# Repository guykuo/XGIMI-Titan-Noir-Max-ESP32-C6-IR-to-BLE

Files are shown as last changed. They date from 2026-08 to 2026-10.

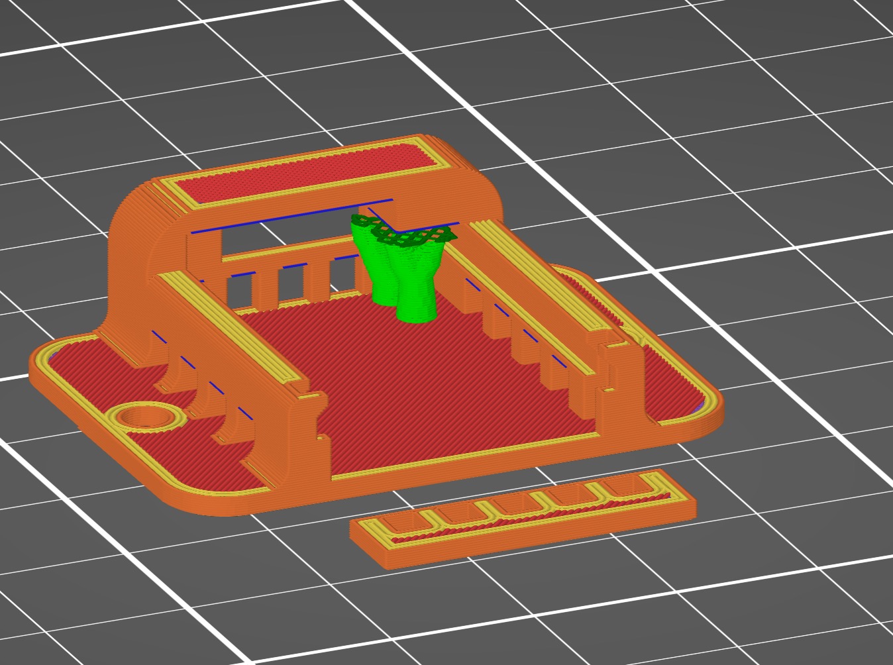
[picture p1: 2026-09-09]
esp32-c3-with-OLED-mount-slim/where_to_add_support_for_print.jpg

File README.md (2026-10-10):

# XGIMI Titan Noir IR Remote via ESP32

banner for git

Titan Noir projectors lack IR control capability and only accept bluetooth signals. This project works around that limitation by translating infrared signals into bluetooth commands the Titan Noir projectors accept. Typical use is to add an Xgimi Titan Noir to a universal IR remote. Depending on which IR code set you choose, you can add as a completely new projector or have the XTN projector masquerade as an existing projector already in your remote. This project runs on low cost ESP32 board.

## Requirements

*   A BlueTooth BLE Capable ESP32 Board. Two boards detailed here are...
    * ESP32-C3 SuperMini dev board with integrated 0.42-inch OLED display (my preferred board)
    * ESP32-C6-WROOM-1 (also good choice)

*   IR sensor module (three pin) for ESP32
    
*   XGIMI Titan Noir Max and its original Bluetooth remote
    
*   Windows, macOS or Linux computer with Bluetooth and Python 3.14 or newer
    
*   Data capable USB cable

This project implements IR translation to Xgimi Titan Noir bluetooth. The parent fork uses Home Assistant HID connectivity. Although Home Assistant has been retained in this project, it is not discussed here. Please see mrmachine's original github if you need _Home Assistant_ usage information.

Turning on the Xgimi Titan Noir projector requires use of the original Xgimi remote wake token. This translator can acquire that token by sniffing your original remote with the ESP32. 

Optionally, you can perform a more tedious, manual capture of your remote's wake token. Then, process that hexadecimal sequence into a secrets.yaml file. It is much easier to skip that process and let the translator ESP32 sniff and capture the wake token.
  
## What You Will Accomplish
Getting the translator to work requires you to...

* Choose which IR code set to translate
* Obtain ESP32 board and IR sensor to be this translator
* Connect ESP32 board to IR sensor (three wires)
* Create a copy of make-esp32-TEMPLATE.yaml
* Rename it something like make-my-translator.yaml
* Edit make-my-translator.yaml to specify name for your remote, which ESP32 board you are using, and which IR translation map.
* Create compiler evironment
* Compile your new ESP32 firmware and flash it to your ESP32 board.
* Set up your universal remote to use the IR mapped codes. 
       (If you chose an IR mapping which matches a projector already in your remote, 
       your remote can simply control the XTN as that existing projector)

# Layout of this Git
Project Git is arranged as below. You will find make, hardware, and IRmap files that are combined to create your own combination of IR code set translation and particular ESP32 board the translator is to run upon.
project git layout

Available hardware boards are in ir-common-kuo/ subdirectory.

## IR Profiles
This translator project has several "factory" IR profiles built-in. You and can also learn up to five new IR remote profiles if none of the factory profiles are suitable.

The "factory" IR profiles, were selected to avoid conflicts in a home theater.
One should usually choose one that does not conflict with existing devices in your system.

An alternative strategy is to intentionally select a projector that is already configured in your universal remote but being replaced.
This lets the Titan Noir masquerade as the old projector without reconfiguring your universal remote. However, the old projector cannot be
simultaneously used under masquerading strategy.

These "factory" IR profiles have known working IR code sets ...

| | |
| :--- | :--- |
| **benq-w5800** | BenQ W5800 projector |
| **epson-pro-cinema-LS1200** | Epson Projectors |
| **hisense-50u6g** | Hisense 50U6G TV |
| **jvc-hr-S9600u** | JVC HR-S9600U VCR |
| **jvc-rs2-codeset-A** | JVC Projectors code set A - default | 
| **jvc-rs2-codeset-B** | JVC Projectors code set B - alt code set | 
| **LG-cinebeam-hu810p** | LG Cinebeam HU810P projector |
| **optoma-UHD50X** | Optoma UHD50X projector |
| **sony-VPL-XW600ES** | Sony VPL-XW600ES projector |
| **sony-XBR-77A9G** | Sony XBR-77A9G TV |
| **tivo-roamio-TCD846500** | TiVo Roamio |
| **AWOL-projector** | AWOL Aetherion Max |
| **Panasonic** | Panasonic projectors. WIP IR mapping |

## Hardware Definition Packages
ESP32 boards are defined in ir-common-kuo/ as hardware.yaml files. These hardware files contain board specific information used to create the translator firmware. Several board types are supplied. You can also create your "hardware" file to support a new ESP32 board type or to customize GPIO assignments.

Supplied hardware files are for ESP32 boards listed in descending order of author preference for use as IR translator ...

* hardware-esp32-c3-0.42-OLED.yaml         # supports built-in 0.42 inch OLED display
* hardware-esp32-c6-wroom-1.yaml            # recommend add external 0.9 inch i2c OLED display
* hardware-waveshare-s3-lcd-1.47B.yaml     # Quirk: requires IR sensor WITHOUT LED (VS1838B)
* hardware-heltec-hiletgo-s3-0.96-OLED-v3.yaml # Quirk: Needs special cable for serial logging
* hardware-lafvintech-c6-lcd-1.47.yaml      # May need physical reset after flashing.
* hardware-hosyond-s3-lcd-3.5-touch.yaml
* hardware-waveshare-c6-lcd-1.47.yaml
* hardware-waveshare-s3-touch-lcd-2.8.yaml
* hardware-ideaspark-esp32-classic-OLED.yaml # Quirk: usb-micro cable, small RAM
* hardware-m5stack-pico-d4-atom-lite.yaml  # supports external 0.9 inch i2c OLED display

Look in the hardware file for actual GPIO pins for IR receiver and optional i2c display
  
# The Hardware
## Selecting an ESP32 Board
I recommend using an ESP32-C3 with on-board OLED display. Although it is possible to sniff tokens "blind," the OLED display gives better feedback during setup and troubleshooting IR codes. Boards that lack a display are also usable, but you will only have LED flashes for feedback during setup. 

## Boards Tested and Known to Work..

### ESP32-C3 with built in 0.42 OLED display. Many clones are available.
esp32 c3 OLED

[Here is a good quality set of 3 including breakout boards](https://www.amazon.com/dp/B0G6YT4ZQ3)

[A cheaper, usable clone with thinner PCB and often less well aligned OLED display ](https://www.amazon.com/dp/B0F59L9RMR)

<br>
<br>

### ESP32-C6-WROOM-1
The [ESP32-C6-WROOM-1](https://www.amazon.com/dp/B0H1GGL9L1?ref=ppx_yo2ov_dt_b_fed_asin_title&th=1) does not have a display, but does have a multi-color neopixel LED that gives some feedback. 
ESP32-C6-WROOM-1

You can optionally connect a [SSD1306 128x32 0.91-inch OLED display module](https://www.amazon.com/dp/B0GX9245FD) to this board. One might even connect the OLED display only during setup and troubleshooting. Support for adding a display is already in the hardware-c6.yaml file. See that file to learn which pins need to be connected for the display.

0 91-inch OLED display module

<br>
esp32-c6-with-LCD

<br>

## Other ESP32 Boards

If you want to use an ESP32 board other than the ones herein, be certain it has at least bluetooth version 4.2 and BLE (Bluetooth Low Energy) capability. Otherwise, power-on broadcast to Xgimi projector will not work.

Board series that should work:

*   ESP32-S3 (uses more electricity than C3 and C6)
*   ESP32-C3
*   ESP32-C6
*   ESP32 pico d4
*   ESP32 (esp32dev)
    
<br>
Boards that will NOT work

*   ESP32-S2 series (no bluetooth)
*   ESP32-P4 series (no bluetooth)
    
<br>
Each variation of ESP board has its own pinout and specific GPIO pins suitable for for IR signal input. It is particularly important to obtain pinout information and know which GPIO pins are actually free for use (not strapping pins or already assigned to other board functions). Because that process can be overwhelming, four board configuration "hardware" files have been supplied. These pre-define board type and pinouts. Most likely, you can simply specify one of the supplied hardware files within your make file.

Hardware files provided have already been configured for those specific boards. Easiest way to proceed is to use one of the exact same boards as I have for this project. If you follow the same board selection and pin wiring that I made, you can directly use one of the supplied hardwared files when creating an IR to Bluetooth translator.

### Using Other ESP Boards

Skip this step if you are using one of already tested boards. To use a different board, obtain its pinout diagram and identify a free GPIO pin suitable for IR input. Beware that some GPIO pins are used for special functions such as boot strapping, timing signals, or may be allocated to devices on the PC board.

Once you know the board pinout and identify an appropriate GPIO pin, make a copy of one of my "hardware" files within ir-common-kuo directory. Name your copy uniquely and and customize it for your particular board.

Adjust values in your hardware yaml for your particular board.

```yaml
# ============= BEGIN Configuration Options KUO ==========

substitutions:
  pin_ir_receiver: GPIO1   # IR sensor. 
  pin_indicator_LED: GPIO8 # LED indicator (both ESP32-C3 and C6)
  pin_action_btn: GPIO9     # use boot button for actions. Both ESP32-c3 and ESP32-C6 use pin 9 for boot button. 
  wifi_tx_power: "12dB"     # wifi power for this board.

# Core Architecture Declaration
esp32:
  board: esp32-c3-devkitm-1
  framework:
    type: esp-idf
  
# i2c Display Pins
i2c: 
  sda: GPIO5
  scl: GPIO6
  frequency: 400kHz
  scan: false # to prevent startup crashes during boot scans
  id: bus_a
  
# ============= END Configuration Options KUO ==========

```

Most users are better off obtaining one of the already tested and known working ESP32 boards.

### ESP32-C6-WROOM-1 Pinout and GPIO Pin Selection Example

ESP32-C6-WROOM-1 board has GPIO10 freely usable as input for I used as IR signal input. Pin GPIO10 has already been specified in the "make" files provided in this project. I have marked the connectors of interest on its pinout diagram.
pinouts esp32-c6-wroom-1-marked

### Adafruit ESP32-C6-DevKitC-1 N8 Pinout and GPIO Pin Selection Example

Although this is also an ESP32-C6 board, its pinout differs from above C6 board. I give this as a reminder that when selecting other boards, you MUST obtain its pinout diagram to know which connectors are to be used. On this alternative board, GPIO 10, GND, and 3V are in totally different places. Also GPIO 10 is not pre-assigned and available to use as IR receiver pin. If your board already has GPIO 10 unavailable, you would need to to create a new hardware file with the correct specifications for board and pins.

5672_esp32-c6-devkitc-1-pin-layout

### ESP32-C3 SuperMini Dev Board with Integrated 0.42-inch OLED Display Example

Lonely Binary's ESP32-C3 OLED board has GPIO01 usable for IR signal input. GPIO01 is on same side as its 3V and Gnd connectos, making wiring simpler than GPIO pins on the opposing edge of the board.
esp32-c3 with OLED pins marked

### Completed ESP32 Boards

Here are two ESP32-C6-WROOM-1 boards wired with two different style IR sensors.
ir to xgimi BLE completed

Here are ESP32-C3 OLED boards. My firmware displays inbound IR codes and equivalent Xgimi projector translation.
oled esp32-c3

Such tiny boards do the job and provide good feedback via OLED display. Flexible sensor wire leads allow turning LED and OLED away from viewer while keeping IR sensor pointed in direction of IR signal. UV cured resin encapsulates IR sensor wire joints in this example.

ESP32 C3 with IR sensor

## Powering Your ESP32 Board

ESP32 boards require very modest power for operation. Any stable USB-C power supply should suffice.

[These work well](https://www.amazon.com/dp/B0DZ6J62C3) and include a varied length assortment of **data capable** cables.

usbc power supply

## IR Sensor

Your IR sensor module needs three connections to your ESP32 board.

1.  IR signal --> GPIO pin (actual pin varies with board)
2.  IR Gnd --> Ground
3.  IR Vcc --> 3V (Avoid connecting Vcc to 5V to avoid risk of ESP32 board damage)

Here are pinouts of two styles of IR sensors and the correct connection points on a ESP32-C3 with built in OLED display.
pinouts c3

The IR sensor style that has the small pc board includes a red LED which lights with IR presence. That feedback LED may be useful during troubleshooting, but is not required and can cause issues with some ESP32 boards. Either style of IR sensor will work with ESP32 boards that have no or a small OLED display. If board has larger (> 1 inch) LCD display, IR sensors, like VS1838B,  WITHOUT an indicator LED are recommended. _Some_ boards with large, built-in displays cannot tolerate load of a IR sensor with indicator LED on 3Vcc. Brownout of 3Vcc can cause bootup failure. A plain VS1838B IR sensor draws less current and is less likely to cause 3Vcc brownouts.

A significant percentage (about 20%) of IR sensor I and others have purchased have been defective. Most of those have been sensors with feedback LED. Provided you have correctly wired up your sensor and are using correct hardware file, one way to check IR sensor is to compile with logging set to DEBUG and watch the logs after flashing your board. A defective IR typically shows no signals listed in log as you expose it to IR signals. There should be info lines printed in log as each IR signal arrives. If nothing shows in log, the sensor is dead.

Another type of IR sensor defect is a noisy sensor that reports signals even when there are none. Physcially shielded sensor from all IR, if you continue to see unrecognized IR signals written to the log, that sensor is noisy and should be replaced.

Here is an alternative board I have also tested, ESP32-C6-WROOM-1. This one does not have a built-in display, but this project will run on it and uses its single light to give feedback.

pinouts c6

# How Bluetooth to Titan Noir Works

When the projector is awake, the ESP32 maintains a bonded Bluetooth HID connection and sends the same keyboard or consumer-control reports captured from the original remote. Settings Menu and Focus use the two distinct short/alternate reports produced by the physical remote. Immediate power-off holds the Power report for the confirmed 1500 ms duration.

When the projector is fully asleep, Power On broadcasts all 256 rolling-counter values with the original remote's stable 15-byte wake token. There is no deliberate delay between advertisements. A connection-state guard prevents a wake burst while the projector is already connected, avoiding advancement of the projector's rolling-code state at the wrong time.

The firmware contains the tested Titan Noir Max HID descriptor and button map.

In the translator project, your wake token is usually sniffed and stored directly on your ESP32 board. It can optionally be in the `secrets.yaml`, but is not required to be in `secrets.yaml`.

Mrmachine already captured and mapped an original Titan Noir Max remote. We do not need to learn its buttons, HID descriptor, names or Home Assistant entities. That has already been done for us by mrmachine.

# Installing This Software on ESP32

Watch the video (https://www.youtube.com/watch?v=Q5G-mbGrfUs)

## 1\. Download this Git to your computer.
Cloning and downloading controls are within Github green "<> Code" button.

gihub directory clone

Expand the downloaded archive.

<br>

## 2\. Create a virtual environment, and install needed tools
### Change working directory of Powershell or Terminal to be the folder containing this Git

Launch PowerShell or Terminal (which depends on your OS).

Type cd -space-

Drag directory of this project into terminal window. Dragging directory into terminal window enters the filepath for you.

Type a return

That should set your shell window working directory to be the one containing this Git.

### Install Python environment
Type in two commands to create python compile and required elements in the Git folder. This readies things for compiling with Python

On MacOS or Linux

```sh
python3 -m venv .venv
.venv/bin/python -m pip install -r requirements.txt
```

On Windows PowerShell or Command Prompt:

```powershell
py -3 -m venv .venv
.venv\Scripts\python.exe -m pip install -r requirements.txt
```

## 3\. OPTIONAL STEP - Manually Capture Your Remote's Token
<details>
<summary>💡 <b>Manual wake token capture</b> (Click to expand)</summary>

You do not have to do this step. The only reason to do so is to have a "default" backup copy of your Xgimi wake token built into the firmware in case you delete the learned token. Generally, including a wake token in secrete.yaml can be skipped because it is so easy to sniff the token with the board running my firmware.

Physically unplug the projector so it cannot reconnect to the original remote. 
Turn Bluetooth on and grant the terminal Bluetooth access if the operating system asks.

Run the bluetooth capture script:

On MacOS or Linux

```sh
.venv/bin/python scripts/capture_wake_token.py --duration 30
```

On Windows Powershell

```powershell
.venv\Scripts\python.exe scripts\capture_wake_token.py --duration 30
```

Keep the remote close to the computer and press its Power button several times during the scan. A trustworthy capture has a stable 15-byte tail and at least two distinct first-byte rolling-counter values.
</details>

## 4\. Create `secrets.yaml` 

You must create a secrets.yaml file using the below script .<b>

If you did the optional step of manually capturing a wake token, substitute the AA:BB:CC:DD:EE:FF:00:11:22:33:44:55:66:77:88 in the script with your manually captured token.
Otherwise, just leave AA:BB:CC:DD:EE:FF:00:11:22:33:44:55:66:77:88 as a placeholder.<br>
<br>
<br>
This script generates the API key and strong OTA/fallback-access-point passwords using Python's secure random generator:

MacOS or Linux

```sh
.venv/bin/python scripts/create_secrets.py --token "AA:BB:CC:DD:EE:FF:00:11:22:33:44:55:66:77:88"
```

Windows Powershell

```powershell
.venv\Scripts\python.exe scripts\create_secrets.py --token "AA:BB:CC:DD:EE:FF:00:11:22:33:44:55:66:77:88"
```

Now you should have a secrets.yaml file that (optionally) contains your wake token. 
If you skipped manually capturing a wake token, you will later sniff the token usihg the ESP32 board. Sniffing is easier than manual capture and editing of hex numbers.

The above script refuses to overwrite an existing `secrets.yaml`.
CAUTION: Do not commit your `secrets.yaml` or a personalised firmware binary to GitHub. Both contain device credentials, and the binary also embeds your wake token.

## 5\. Build and Flash Firmware for Your Choice of IR Remote
### Make Files
"Make" files are where you specify desired combination of board type, IR profile, and name your new IR translator. 
A template make files is provided. ***make-esp32-TEMPLATE.yaml***

1 Duplicate make-esp32-TEMPLATE.yaml to create your custom make file<br>
2 Name your custom make file<br>
3 Edit your custom make file

We will name our make file ***makemine.yaml***

Your custom make file should be left in the same directory as the original ***make-esp32-TEMPLATE.yaml*** file.
Also, never move or rename files in ir-common-kuo/ subdirectory<br>
<br><br>
Open ***makemine.yaml*** in a text editor to customize three things within Configuration Options section<br>
You can specify remote name, esp32 board, and default IR profile.<br>
<br><br>
Name of remote is specified by changing name within quotes of line. Here it is *IR to Xgimi Kuo*<br>
* ble_remote_name: "IR to Xgimi Kuo"<br>
<br><br>
Default IR Profile is set by uncommenting one and only one line. Here it is *epson-pro-cinema-LS12000*<br>
You can later override this via profile setting on the ESP32 board.<br>
<br><br>
ESP32 board is set by uncommenting one and only one line. Here it is *hardware-c3.yaml*<br>
<br><br>
```YAML
# ============= BEGIN Configuration Options KUO ======================================================================

# Three things must be configured here
#   ble_remote_name
#   Default IR profile
#   hardware_package

substitutions:
  # 1 ======= ble_remote_name, Bluetooth Name for your IR remote ===========================
  ble_remote_name: "IR Xgimi Kuo"  # (20 char max. No special characters. No underscore) 
 
  # may optionally change these other three names 
  ssid_name:     ${ble_remote_name} # Name of AP wifi network
  friendly_name: ${ble_remote_name} # Displayed name in Home Assitant
  device_name:   esp32-xgimi # formal Home Assitant ID. lowercase a-z, digits 0-9, hyphen (no spaces, no caps, no underscore)

  # 2 ======= Default IR profile. Uncomment one (and only one) ============================

  #def_profile: "0"  # AWOL vision aetherion max
  #def_profile: "1"  # benq-w5800
  def_profile: "2"  # epson-pro-cinema-LS12000
  #def_profile: "3"  # hisense-50u6g
  #def_profile: "4"  # jvc-hr-S9600u
  #def_profile: "5"  # jvc-rs2-codeset-A 
  #def_profile: "6"  # jvc-rs2-codeset-B 
  #def_profile: "7"  # LG-cinebeam-hu810p 
  #def_profile: "8"  # optoma-UHD50X
  #def_profile: "9"  # sony-VPL-XW600ES 
  #def_profile: "10" # sony-XBR-77A9G 
  #def_profile: "11" # tivo-roamio-TCD846500 
  #def_profile: "12" # panasonic projector

packages: 
  # 3 =======  ESP32 board, Uncomment one (and only one) to specify board ===================
  
  hardware_package: !include ir-common-kuo/hardware-esp32-c3-0.42-OLED.yaml         # supports built-in 0.42 inch OLED display
  #hardware_package: !include ir-common-kuo/hardware-esp32-c6-wroom-1.yaml           # supports external 0.9 inch i2c OLED display
  #hardware_package: !include ir-common-kuo/hardware-ideaspark-esp32-classic-OLED.yaml
  #hardware_package: !include ir-common-kuo/hardware-lafvintech-c6-lcd-1.47.yaml
  #hardware_package: !include ir-common-kuo/hardware-m5stack-pico-d4-atom-lite.yaml  # supports external 0.9 inch i2c OLED display
  #hardware_package: !include ir-common-kuo/hardware-hosyond-s3-lcd-3.5-touch.yaml
  #hardware_package: !include ir-common-kuo/hardware-waveshare-c6-lcd-1.47.yaml
  #hardware_package: !include ir-common-kuo/hardware-waveshare-s3-touch-lcd-2.8.yaml
  #hardware_package: !include ir-common-kuo/hardware-waveshare-s3-lcd-1.47B.yaml     # requires IR sensor WITHOUT LED like VS1838B
  #hardware_package: !include ir-common-kuo/hardware-heltec-hiletgo-s3-0.96-OLED-v3.yaml   # Needs specialcable for serial logging

  #hardware_package: !include ir-common-kuo/HARDWARE.YAML # Or uncomment this line and replace HARDWARE.YAML with your file.

# === END Configuration Options KUO =========================================================================

```  
### 5a Build and Flash the Firmware
Once our make file has been created and customized, you are ready to compile and flash firmware to ESP32 board.
Connect your ESP32 board with USB. <br>

Validate, compile and flash:

MacOS or Linux

```sh
.venv/bin/esphome run makemine.yaml
```

Windows Powershell

```powershell
.venv\Scripts\esphome.exe run makemine.yaml

```

Once firmware is compiled, you should be presented with a choice of how to flash your ESP32 board.
Select the serial upload function. Over the air upload or update will NOT work with this project.
Even though the build environment may offer a wireless upload option, always use USB serial upload.

Select the ESP32's USB serial port when prompted `COM…` on Windows or `/dev/…` on macOS/Linux). 
If no port appears, install the USB serial driver required by the ESP32 USB interface and try again.

## 6\. Learning Wake Token from Xgimi Remote.
IMAGE ALT TEXT HERE (https://www.youtube.com/watch?v=Twvc1mUYd0o)

Unless your secrets.yaml already has a valid wake token, your ESP32 translator needs to learn a wake token from your original Xgimi remote.
Sniffing for the wake token should be done with projector power disconnected because you will be pressing the remote's power button repeatedly.

- Remove AC power from Xgimi Titan Noir Projector
- ESP32 should be plugged into 5 volt USB-C power

- There are two ways to start Sniffing for wake tokens. Easiest is to single click the BOOT button of your ESP32 board. If your translator is already on the profile for your IR remote, the other option is to press the correct button on your IR remote that starts token sniffing. 

A light will come on to indicate sniffing mode. Sniffing remains active for 20 seconds. 
    
- Repeatedly press power button on Xgimi remote with it near your ESP32 board.
      Usually, just 1 to 2 presses are needed to sniff a valid token. 
      If you have an ESP32-C3 with built-in OLED display, sniff mode and capture will be shown.
      On boards lacking a display, light will flash 8 times indicating capture of new token.
      If light flashes 3 times, captured token was identical to one already stored.

- Wait at least five seconds to let the ESP32 commit the token to NVS flash storage.
     Once flashed to permanent storage, the learned token persists across power and boot cycles.
     Normally, there is no need to clear a learned token, unless you wish to revert to the one
     specified in secret.yaml. Because sniffing a token is so simple, you likely did not manually
     capture and place one in your secrets.yaml. Easiest is to sniff with the ESP board.

### What the Token Buttons on Your IR Remote Do
  - Token Sniff - ESP32 sniffs for an Xgimi a wake token for 20 seconds. If one is captured, It is stored into NV storage.
  - Token Clear - Must be pressed and confirmed with OK button. Stored token is removed from NV storage. Active wake token becomes the one supplied in secrets.yaml
  - Token Recall - Makes currently stored token the active token. Shows on display, if one is present). This is useful to verify token was sniffed correctly.

Three buttons on your remote are assigned to control wake token. The actual buttons depend on which IR profile you are using.
|IR Profile | Token Action | Button |
| ---- | ---- | ---- |
| AWOL Aetherion | Sniff | Disney |
| AWOL Aetherion | Clear | -none- |
| AWOL Aetherion | Recall | -none- |
| ---- | ---- | ---- |
| BenQ W5800 | Sniff | info |
| BenQ W5800 | Clear | invert |
| BenQ W5800 | Recall | 3D |
| ---- | ---- | ---- |
| Epson Pro Cinema | Sniff | Frame Interp |
| Epson Pro Cinema | Clear | RGMCMY |
| Epson Pro Cinema | Recall | Pattern |
| ---- | ---- | ---- |
| Hisense 50U6G | Sniff | 4 |
| Hisense 50U6G | Clear | 5 |
| Hisense 50U6G | Recall | 6 |
| ---- | ---- | ---- |
| JVC Projectors | Sniff | cinema |
| JVC Projectors | Clear | natural |
| JVC Projectors | Recall | gamma or HDR |
| ---- | ---- | ---- |
| LG Cinebeam | Sniff | 4 | 
| LG Cinebeam | Clear | 5 |
| LG Cinebeam | Recall | 6 |
| ---- | ---- | ---- |
| Optoma UHD50X | Sniff | user 1 | 
| Optoma UHD50X | Clear | user 2 |
| Optoma UHD50X | Recall | user 3 | 
| ---- | ---- | ---- |
| Sony VPL-XW600ES | Sniff | Brt Cinema | 
| Sony VPL-XW600ES | Clear | Brt TV |
| Sony VPL-XW600ES | Recall | User |
| ---- | ---- | ---- |
| Sony XBR-77A9G | Sniff | 4 | 
| Sony XBR-77A9G | Clear | 5 |
| Sony XBR-77A9G | Recall | 6 |
| ---- | ---- | ---- |
| TiVo Roamio | Sniff | 4 | 
| TiVo Roamio | Clear | 5 |
| TiVo Roamio | Recall | 6 |

## 7\. Selecting and Learning Profiles
### Selecting Profile
* Double-click boot button to put translator into profile setting mode. <br><br>

* Press a button on your desired IR remote and the translator should switch to that remote's profile.<br>
<br><br>
The translator listens for an IR signal. Identifies the projector by matching that signal against signals it knows. User learned remotes have higher precedence over "factory" profiles. Once a profile is set, the ESP32 will listen only for that profile and translate them to Xgmi Titan Noir bluetooth commands.<br>

### Learning a new Profile from IR Remote
In case none of the "factory" profiles are suitable for you system, you can also teach the translator a new IR profile. Learning mode requires a display on your ESP32 board or having the ESP32 board connected to a serial logging session. (Technically, learning will work without a display or log, but that would entail blindly pressing a sequence of 27 IR buttons perfectly.

* Triple-click boot button to enter learning mode.
* As each button namem appears on screen, press the corresponding button on your IR remote
* Once done with all buttons, you select which memory slot to store your new profile via the remote.
<br><br>
  OK = memory 0<br>
  Up = memory 1<br>
  Down = memory 2<br>

### Learning IR Profile without Display or Log
It is possible, but more prone to error, to press the 27 button sequence of learing an IR profile. LED flashes help users keep track of where they are in sequence.

Triple Click boot button. LED flashes 3 times indicating IR learn mode

Diagram of button sequence and LED flashes. You can interpet the flashes as happening before a button (indicating which button to press next) or you can interpret as the flash confirming the button you just pressed. First column shows flash before button press. 3rd column shows flash after button press.
IR learn profile LED flash sequence

## 8\. Add Your ESP32 Remote as to Projector as Additional Bluetooth Device
Turn on your projector with its original remote control. Within settings add your new IR translator as another Bluetooth remote.
<br><br>
Keep the original remote paired as well.
<br>
<br>

## 9\. Macro Recording and Playback
You can record up to 9 macros (sequences of button presses and holds) for later playback. Unlike recording and playback on most universal remotes that use a fixed inter-button delay during playback, this IR project records your cadence and attempts to play back actions with approximately the same speed and pauses you make during recording. This lets you naturally pace macro sequencess to match projector response speed. If you pause to let the projector open a menu or complete an action, the playback will simiarly pause.

To record a macro, press the "macro_record" button of your remote once. Then, press your sequence of buttons. Once done recording, press the "macro_record" button ONCE.
The next button you press will be assigned the just recorded macro. The buttons that can accept a macro are the D-Pad buttons (up, down, left, right, enter) and the four shortcut buttons. Macros can be up to 16 buttons presses in length

To play back a macro, press the "macro_play" button of your remote once. Then, press the button to which your macro was previously assigned. You macro sequence will play back.

To erase all macros, _while you have macro recording mode on_, press and hold the BOOT button at least five seconds. 

# Xgimi Command and IR Remote Button Tables
## Tivo Roamio to Xgimi Titan Noir Mapping
|Xgimi Remote Command | Tivo Remote | (0x3085) + Command |
| :--- | :--- | :--- |
| power_on | tv power (as discrete on) | 0xE010 |
| power_off | live TV (as discrete off) | 0xE011 |
| power_off_alt | 0 | 0xC031 |
| cursor_up | arrow up | 0xE014 |
| cursor_down | arrow down | 0xE016 |
| cursor_left | arrow left | 0xE017 |
| cursor_right | arrow right | 0xE015 |
| cursor_enter | select | 0xE019 |
| back | zoom | 0xB044 |
| settings_menu | tivo | 0xF00C |
| settings_menu | tivo (myHarmony version) | 0xF00D |
| game_menu | guide | 0xC036 |
| home | channel up | 0xE01E |
| input | input | 0xC034 |
| picture | into | 0xE013 |
| focus_auto | 7 | 0xD02E |
| focus_manual | 8 | 0xD02F |
| shortcut_1 | A yellow | 0x9060 |
| shortcut_2 | B blue | 0x9061 |
| shortcut_3 | C red | 0x9062 |
| shortcut_4 | D green | 0x9063 |
| volume_up | volume up | 0xE01C |
| volume_down | volume down | 0xE01D |
| mute | mute | 0xE01B |
| token_sniff | 4 | 0xD02B |
| token_clear | 5 | 0xD02C |
| token_recall | 6 | 0xD02D |
| macro_record | record | 0xD020 |
| macro_play | play | 0xD021 |

## Hisense 50U6G to Xgimi Titan Noir Mapping
|Xgimi Remote Command | Hisense Remote Button | (0xEA15) + Command |
| :--- | :--- | :--- |
| power_on | discrete power on | 0xF708 |
| power_on_alt | discrete power on (variant) | 0x8E71 |
| power_off | discrete power off | 0xEF10 |
| power_off_alt | 0 | 0x8D72 |
| cursor_up | arrow up | 0xA956 |
| cursor_down | arrow down | 0xA857 |
| cursor_left | arrow left | 0xA758 |
| cursor_right | arrow right | 0xA659 |
| cursor_enter | select | 0xA55A |
| back | back | 0xFB04 |
| home | home | 0xBC43 |
| input | input | 0xF40B |
| settings_menu | menu | 0xB54A |
| settings_menu_alt | menu (variant) | 0x718E |
| game_menu | apps | 0x35CA |
| picture | channel up | 0xFF00 |
| focus_manual | 7 | 0xE817 |
| focus_auto | 8 | 0xE718 |
| shortcut_1 | yellow | 0xAB54 |
| shortcut_2 | blue | 0xAA55 |
| shortcut_3 | red | 0xAD52 |
| shortcut_4 | green | 0xAC53 |
| volume_up | volume up | 0xFD02 |
| volume_down | volume down | 0xFC03 |
| mute | mute | 0xF609 |
| token_sniff | 4 | 0xEB14 |
| token_clear | 5 | 0xEA15 |
| token_recall | 6 | 0xE916 |
| macro_record | prime video | 0xB847 |
| macro_play | youtube | 0xB649 |

## LG Cinebeam HU810P to Xgimi Titan Noir Mapping
(Some items duplicated to accept alternative buttons)
| Xgimi Remote Command | LG Cinebeam Button | (0xFB04) + Command  |
| :--- | :--- | :--- |
| power_on | power toggle | 0xF708 |
| power_on-alt | Discrete Power On | 0x23DC |
| power_off | Discrete Power Off | 0x2CC3 |
| power_off_alt | 0 | 0xEF10 |
| back | Back / Return | 0xD728 |
| cursor_left | cursor left | 0x7807 |
| cursor_right | cursor right | 0xF906 |
| cursor_up | cursor up | 0xBF40 |
| cursor_down | cursor down | 0xBE41 |
| cursor_enter | OK / Select | 0xBB44 |
| settings_menu | menu | 0xBC43 |
| home | home | 0x837C |
| input | Input Toggle | 0xF40B |
| game_menu | channel down | 0xFE01 |
| picture | Picture Mode | 0xB24D |
| focus_manual | aspect ratio | 0x8679 |
| focus_auto | play | 0x4FB0 |
| shortcut_1 | red | 0x8d72 |
| shortcut_2 | green | 0x8e71 |
| shortcut_3 | yellow | 0x9C63 |
| shortcut_4 | blue | 0x9E61 |
| volume_up | volume up | 0xFD02 |
| volume_down | volume down | 0xFC03 |
| mute | mute | 0xF609 |
| token_sniff | 4 | 0xEB14 |
| token_clear | 5 | 0xEA15 |
| token_recall | 6 | 0xE916 |
| macro_record | netflix | 0xA956 |
| macro_play | play | 0x4FB0 |

## JVC-VCR to Xgimi Titan Noir Mapping
| Xgimi Remote Command | JVC VCR Btn | (0x03C2) + Command |
| :--- | :--- | :--- |
| power_on | power (as discrete) | 0xC2D0 |
| power_on_alt | power (alternate) | 0xC2B8 |
| power_off | discrete off | 0xC258 |
| power_off_alt1 | audio monitor | 0xC2E8 |
| power_off_alt2 | 0 | 0xC2CC |
| back | review | 0xC2C3 |
| cursor_up | cursor up | 0xC241 |
| cursor_up_alt | cursor up (harmony) | 0xC298 |
| cursor_down | cursor down | 0xC218 |
| cursor_down_alt | cursor down (harmony) | 0xC261 |
| cursor_left | cursor left | 0xC2A8 |
| cursor_right | cursor right (harmony) | 0xC228 |
| cursor_enter | OK | 0xC23C |
| settings_menu | menu | 0xC2EC |
| settings_menu_alt | memu (alternate) | 0xC207 |
| home | cancel | 0xC26C |
| game_menu | game menu | 0xC230 |
| input | tv/vcr | 0xC2C8 |
| picture | fast forward | 0xC260 |
| focus_manual | 8 | 0xC214 |
| focus_auto | 7 | 0xC2E4 |
| shortcut_1 | prog | 0xC283 |
| shortcut_2 | prog check | 0xC2BC |
| shortcut_3 | SP/EP | 0xC28C |
| shortcut_4 | skip search | 0xC269 |
| volume_up | start down | 0xC213 |
| volume_down | start up | 0xC293 |
| mute | pause | 0xC2B0 |
| token_sniff | 4 | 0xC224 |
| token_clear | 5 | 0xC2A4 |
| token_recall | 6 | 0xC264 |
| macro_record | 1 | 0xC284 |
| macro_play | 2 | 0xC244 |

## JVC Projector to Xgimi Titan Noir Mapping
The JVC IRmap accomodates several generations of JVC projectors. Buttons on their respective IR remotes have changed over the generations. Some buttons may no longer exist and must be replaced by ones for newer remotes. For this reason, you will see several _alt button mappings for some functions. These let the mapping adapt between older and more current projector remotes.

JVC projectors by default respond to code set A. The can be changed to code set B to avoid control conflicts.
Be aware that you need to use physical buttons on projector (or IP / serial control) to change projector code set if a remote with current codes set is not available.

| Xgimi Command | JVC Projector Btn | (0xCE) + Command |
| :--- | :--- | :--- |
| power_on |  power on | 0xA0 |
| power_off |  power off | 0x60 |
| cursor_up |  up arrow | 0x80 |
| cursor_down |  down arrow | 0x40 |
| cursor_left |  left arrow | 0x6C |
| cursor_right |  right arrow | 0x2C |
| cursor_enter |  enter/ok | 0xF4 |
| settings_menu |  menu | 0x74 |
| back |  exit | 0xC0 |
| home |  hide | 0xB8 |
| game_menu |  dynamic | 0xD6 |
| game_menu_alt |  advanced menu_ | 0xCE |
| input |  input HDMI 1 | 0x0E |
| picture |  input HDMI 2 | 0x8E |
| picture_alt |  picture mode_ | 0x2F |
| focus_manual |  focus - | 0xCC |
| focus_auto |  focus + | 0x8C |
| focus_manual_alt |  color profile_ | 0x11 |
| focus_auto_alt |  gamma settings_ | 0xAF |
| shortcut_1 |  user 1 | 0x36 |
| shortcut_2 |  user 2 | 0xB6 |
| shortcut_3 |  user 3 | 0x76 |
| shortcut_4 |  aspect | 0xEE |
| shortcut_1_alt |  mode 1_ | 0x1B |
| shortcut_2_alt |  mode 2_ | 0x9B |
| shortcut_3_alt |  mode 3_ | 0x5B |
| shortcut_4_alt |  info | 0x2E |
| volume_up |  brightness up | 0x5E |
| volume_down |  brightness down | 0xDE |
| mute |  color temp | 0x6E |
| volume_up_alt |  lens AP_ | 0x04 |
| volume_down_alt |  lens control_ | 0x0C |
| mute_alt |  anamorphic_ | 0xA3 |
| token_sniff |  cinema_ | 0x16 |
| token_sniff_alt |  cinema | 0x96 |
| token_clear |  natural | 0x56 |
| token_recall |  gamma | 0xAE |
| token_recall_alt |  HDR_ | 0xB7 |
| macro_record |  sharp down | 0xFE |
| macro_play |  sharp up | 0x9A |
| macro_record |  CMD_ | 0x51 |
| macro_play |  mpc_ | 0x0F |

## Sony Bravia XBR-77A9G TV to Xgimi Titan Noir Mapping
| Xgimi Command | Sony TV Remote | Hex Code |
| :--- | :--- | :--- |
| power_on | power on discrete | 0x000750 |
| power_on_alt | power (toggle) | 0x000A90 |
| power_off | power off discrete | 0x000F50 |
| power_off_alt | 0 | 0x000910 |
| cursor_left | Arrow Left | 0x0002D0 |
| cursor_right | Arrow Right | 0x000CD0 |
| cursor_up | Arrow Up | 0x0002F0 |
| cursor_down | Arrow Down | 0x000AF0 |
| cursor_enter | Arrow Select | 0x000A70 |
| settings_menu | Action Menu | 0x006923 |
| back | Back | 0x0062E9 |
| home | Home | 0x000070 |
| game_menu | Google Play | 0x003123 |
| input | Input | 0x000A50 |
| picture | TV | 0x000250 |
| focus_auto | subtitle | 0x000AE9 |
| focus_manual | audio | 0x000E90 |
| shortcut_1 | yellow | 0x0072E9 |
| shortcut_2 | blue | 0x0012E9 |
| shortcut_3 | red | 0x0052E9 |
| shortcut_4 | green | 0x0032E9 |
| volume_up | volume up | 0x000490 |
| volume_down | volume down | 0x000C90 |
| mute | mute | 0x000290 |
| token_sniff | 4 | 0x000C10 |
| token_clear | 5 | 0x000210 |
| token_recall | 6 | 0x000A10 |
| macro_record | play | 0x002CE9 |
| macro_play | fast forward | 0x001CE9 |

## Sony VPL-XW600ES Projector to Xgimi Titan Noir Mapping
| Xgimi Command | Sony Projector Remote | Hex Code |
| :--- | :--- | :--- |
| power_on | Power On (discrete) | 0x00003A2A |
| power_off | Power Off (discrete) | 0x00007A2A |
| power_on_alt | Power Toggle (alt discrete On) | 0x0000542A |
| cursor_up | up arrow | 0x0000562A |
| cursor_down | down arrow | 0x0000362A |
| cursor_left | left arrow | 0x0000162A |
| cursor_right | right arrow | 0x0000662A |
| cursor_enter | OK / Enter | 0x00002D2A |
| settings_menu | Menu | 0x00004A2A |
| home | Reset | 0x00006F2A |
| back | Position | 0x00018BE4 |
| game_menu | Game | 0x0006AB54 |
| picture | Photo | 0x000EAB54 |
| input | Input | 0x0000752A |
| focus_manual | Focus | 0x00026B54 |
| focus_auto | Zoom | 0x00046B54 |
| shortcut_1 | Aspect Ratio | 0x00076B54 |
| shortcut_2 | Motion Flow | 0x0000502A |
| shortcut_3 | 3D | 0x000DCB54 |
| shortcut_4 | Color Space | 0x000D2B54 |
| volume_up | CONTRAST | 0x00000C2A |
| volume_down | CONTRAST DOWN | 0x00004C2A |
| mute | Advanced Iris | 0x000FAB54 |
| token_sniff | BRT Cinema | 0x0009AB54 |
| token_clear | BRT TV | 0x0008AB54 |
| token_recall | User | 0x0002AB54 |
| macro_record | BRIGHTNESS DOWN | 0x00007C2A |
| macro_play | BRIGHTNESS UP | 0x00003C2A |

## Epson Pro Cinema LS1200 Projector to Xgimi Titan Noir Mapping
This IRmap also works with other Epson projectors such as the 5050UB
| Xgimi Command | Epson Projector Btn | (0x5583) + Command |
| :--- | :--- | :--- |
| power_on | Power On | 0x6F90 |
| power_off | Power Off | 0x6E91 |
| cursor_up | up arrow | 0x4FB0 |
| cursor_down | down arrow | 0x4DB2 |
| cursor_left | left arrow | 0x4CB3 |
| cursor_right | right arrow | 0x4EB1 |
| cursor_enter | enter | 0x7A85 |
| settings_menu | menu | 0x659A |
| back | ESC | 0x7B84 |
| home | default | 0xC639 |
| game_menu | color mode | 0x708F |
| input | HDMI link | 0xA956 |
| picture | image enhance | 0x55AA |
| focus_manual | skip back | 0xA25D |
| focus_manual_alt | lens (not in MyHarmony) | 0x728D |
| focus_auto | pause | 0xA45B |
| shortcut_1 | reverse | 0xA55A |
| shortcut_2 | play | 0xA15E |
| shortcut_3 | FF | 0xA35C |
| shortcut_4 | skip forward | 0xA05F |
| shortcut_1_alt | HDMI 1 | 0x8C73 |
| shortcut_2_alt | HDMI 2 | 0x8877 |
| shortcut_3_alt | P-in-P (not in myHarmony) | 0x7D82 |
| shortcut_4_alt | PC (not in myHarmony) | 0x629D |
| volume_up | volume up | 0x6798 |
| volume_down | volume down | 0x6699 |
| mute | mute | 0x52AD |
| token_sniff | frame interp | 0x7C83 |
| token_clear | RGBCMY | 0xC23D |
| token_recall | pattern | 0x6996 |
| macro_record | 3D format | 0xC43B |
| macro_play | Aspect | 0x758A |

 ## AWOL Vision Aetherion Max to Xgimi Titan Noir Mapping
| Xgimi Command | AWOL Aetherion Btn | (0xCE00) + Command |
| :--- | :--- | :--- |
| power_on | power on | 0x1AE5 |
| power_off | power off | 0x19E6 |
| cursor_left | left arrow | 0xDB24 |
| cursor_right | right arrow | 0xDA25 |
| cursor_up | up arrow | 0xD926 |
| cursor_down | down arrow | 0xD827 |
| cursor_enter | ok | 0xD728 |
| settings_menu | menu | 0xA55A |
| back | back | 0xA35C |
| home | home | 0xA45B |
| game_menu | Netflix | 0x23DC |
| input | input select | 0xED12 |
| picture | Google Assist | 0x1EE1 |
| focus_manual | AI Box | 0x25DA |
| focus_auto | Prime Video | 0x22DD |
| shortcut_1 | HDMI 1 | 0x18E7 |
| shortcut_2 | HDMI 2 | 0x17E8 |
| shortcut_3 | HDMI 3 | 0x16E9 |
| shortcut_4 | Live TV | 0x1DE2 |
| volume_up | vol up | 0xF50A |
| volume_down | vol down | 0xF40B |
| mute | mute | 0xE41B |
| token_sniff | Disney | 0x21DE |
| token_clear | none | 0x97 |
| token_recall | none | 0x97 |
| macro_record | select profile | 0x27D8 |
| macro_play | Youtube | 0x24DB |

## BenQ W5800 Projector to Xgimi Titan Noir Mapping
| Xgimi Command | BenQ Projector Btn | (0x3000) + Command |
| :--- | :--- | :--- |
| power_on | power on | 0xB04F |
| power_off | power off | 0xB14E |
| cursor_up | up arrow | 0xF40B |
| cursor_down | down arrow | 0xF30C |
| cursor_left | left arrow | 0xF20D |
| cursor_right | right arrow | 0xF10E |
| cursor_enter | ok | 0xEA15 |
| settings_menu | menu | 0xF00F |
| back | back | 0x7A85 |
| home | default | 0x8778 |
| game_menu | guide | 0xEA15 |
| input | source | 0xFB04 |
| picture | picure mode | 0xEF10 |
| focus_manual | aspect | 0xEC13 |
| focus_auto | auto | 0xF708 |
| shortcut_1 | brightness | 0xE916 |
| shortcut_2 | contrast | 0xEE11 |
| shortcut_3 | dynamic iris | 0x837C |
| shortcut_4 | light mode | 0xCF30 |
| volume_up | gamma | 0xA15E |
| volume_down | sharp | 0x817E |
| mute | eco blank | 0xF807 |
| token_sniff | info | 0xF30C |
| token_clear | invert | 0x629D |
| token_recall | 3D | 0x639C |
| macro_record | color temp | 0xA05F |
| macro_play | color manage | 0xA45B |

## Optoma UHD50X Projector to Xgimi Titan Noir Mapping
| Xgimi Command | Optoma Projector Btn | (0xCD32) + Command |
| :--- | :--- | :--- |
| power_on | power on | 0xFD02 |
| power_off | power off | 0xD12E |
| cursor_left | left arrow | 0xEF10 |
| cursor_right | right arrow | 0xED12 |
| cursor_up | up arrow | 0xEE11 |
| cursor_down | down arrow | 0xEB14 |
| cursor_enter | ok | 0xF00F |
| settings_menu | menu | 0xF10E |
| back | sleep | 0x9C63 |
| input | input HDMI 1 | 0xE916 |
| game_menu | input HDMI 2 | 0xCF30 |
| picture | mode | 0xFA05 |
| focus_manual | aspect | 0x9B64 |
| focus_auto | DB | 0xBB44 |
| shortcut_1 | input VGA 1 | 0xE41B |
| shortcut_2 | input VGA 2 | 0xE11E |
| shortcut_3 | input video | 0xE31C |
| shortcut_4 | input YPbPr | 0xE817 |
| volume_up | 3D | 0x7689 |
| volume_down | keystone | 0xF807 |
| mute | mute | 0xAD52 |
| token_sniff | user 1 | 0xC936 |
| token_clear | user 2 | 0x9A65 |
| token_recall | user 3 | 0x9966 |
| macro_record | brightness | 0xBE41 |
| macro_play | contrast | 0xBD42 |

# Recent Changes:
Macro record and playback
Bluetooth raw code support (BKEY, BCON) via CSV download/upload
AWOL Aethrion profile verified 

#Webserver
This project includes a webserver which can be reached at your ESP32 board's IP address after it has been provisioned onto your local network via the usual Home Assistant device captive AP setup.

Credentials for webserver are admin / fallback_ap_password from your secrets file



_Active Profile_ is the profile that is currently being used for IR mapping to Xgimi bluetooth.<br><br>

_Select Target Profile Slot:_ sets which profile you want to work with.<br><br>

_Activate Selected Profile_ sets selected profile as the active profile for IR mapping.<br><br>

_Download CSV_ downloads selected profile as a CSV file.<br><br>

_Choose file_ lets you chose a CSV to upload. You should have target slot set to one of the custom memories for upload. If you attempt to upload to a factor slot, it will instead be uploaded into memory slot 0.<br><br>

_Upload CSV_ performs the actual upload. Click this after you have set a target profile slot into which to upload.<br><br>

Here is a sample CSV.
The META row is slot#, profile name, protocol, device address, token_clear_arming_code, token_clear_fire_code

The KEY rows are command, xgimi-action, button-name-on-original-remote

sample csv

In addition to letting you save and restore learned profiles, you can also override a factory profile. To do so, download a factory profile, edit it and uploading into a custom slot. During profile setting, the system searches for a match starting within custom profiles in reverse order. It will find your modified version first and use that instead of a matching factory profile.

## Scope and safety

This was captured and tested on an XGIMI Titan Noir Max. Other XGIMI models or remote revisions may use a different HID map or wake format. This project is independent and is not affiliated with XGIMI, M5Stack, ESPHome or Home Assistant.

## License

This project is distributed under GPLv3 because its adapted ESPHome C++ runtime code is GPLv3. See `LICENSE` and `THIRD_PARTY_NOTICES.md`.

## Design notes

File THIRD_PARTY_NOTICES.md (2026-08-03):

# Third-party notices

`components/esp32_ble_server/` is adapted from the ESPHome project. ESPHome's
C/C++ runtime is GPLv3; its Python code and other portions are MIT licensed.
The upstream combined licence notice is preserved in
`licenses/ESPHome-LICENSE.txt`. ESPHome source is available at
<https://github.com/esphome/esphome>.

ESPHome, Home Assistant, XGIMI and M5Stack names and marks belong to their
respective owners.

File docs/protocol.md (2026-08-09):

# Sanitised Titan Noir Max Bluetooth HID reference

This model-wide reference was captured from an original XGIMI Titan Noir Max
remote with an ESP32 HID host. Per-user identifiers and the wake token are
deliberately omitted.

## Identity and descriptor

- Advertised name: `XGIMI RC`
- Manufacturer string: `Seneasy`
- HID reports: keyboard report ID 1 (8 bytes) and consumer-control report ID 2
  (6 bytes)
- Release: an all-zero report of the same type

HID report descriptor:

```text
05010906A10105070906A101850195087508150025FF190029FF8100C0050C0901A1018502950375101500269C0219002A9C028100C0C0
```

## Captured reports

| HA action | Type | Press data |
| --- | --- | --- |
| Cursor Up | Keyboard | `00 00 52 00 00 00 00 00` |
| Cursor Down | Keyboard | `00 00 51 00 00 00 00 00` |
| Cursor Left | Keyboard | `00 00 50 00 00 00 00 00` |
| Cursor Right | Keyboard | `00 00 4F 00 00 00 00 00` |
| Cursor Enter | Keyboard | `00 00 28 00 00 00 00 00` |
| Home | Keyboard | `00 00 4A 00 00 00 00 00` |
| Back | Keyboard | `00 00 29 00 00 00 00 00` |
| Settings Menu  | Keyboard | `00 00 41 00 00 00 00 00` |
| Game Menu | Keyboard | `00 00 65 00 00 00 00 00` |
| Focus (Auto) | Keyboard | `00 00 44 00 00 00 00 00` |
| Focus (Manual) | Keyboard | `00 00 3D 00 00 00 00 00` |
| Volume Up | Keyboard | `00 00 80 00 00 00 00 00` |
| Volume Down | Keyboard | `00 00 81 00 00 00 00 00` |
| Power | Keyboard | `00 00 7F 00 00 00 00 00` |
| Mute | Consumer | `BD 01 00 00 00 00` |
| Input | Consumer | `BC 01 00 00 00 00` |
| Picture | Consumer | `23 02 00 00 00 00` |
| Shortcut 1 | Consumer | `1D 02 00 00 00 00` |
| Shortcut 2 | Consumer | `1F 02 00 00 00 00` |
| Shortcut 3 | Consumer | `21 02 00 00 00 00` |
| Shortcut 4 | Consumer | `22 02 00 00 00 00` |

Settings and Focus classify a hold inside the original remote and emit their
alternate report as a short tap after the threshold; the ordinary code is not
sent first. Power stays active until release and is held by this firmware for
the confirmed 1500 ms duration to skip the shutdown confirmation.

### Original remote tap timing

A timestamped HID-host capture on 2026-08-09 measured natural presses of the
original remote. Each tap produced one key-down report followed by one all-zero
release report; a held arrow produced no repeated reports.

| Button | Natural taps | Observed key-down durations | Mean |
| --- | --- | --- | ---- |
| Right  | 10 | 90, 100, 90, 100, 90, 90, 110, 110, 90, 90 ms | 96 ms |
| Left | 10 | 90, 90, 130, 130, 150, 100, 150, 150, 140, 150 ms | 128 ms |
| Up | 5 | 90, 90, 90, 90, 100 ms | 92 ms |

The combined median is 100 ms and the combined mean is 108 ms. A separate
800 ms Right hold consisted only of the initial key-down and final release.
Ordinary cloned taps therefore preserve 100 ms of active key-down time rather
than sending press and release notifications back-to-back.

The held-power button and Home Assistant's stateful Power switch both request
desired Power off. Once the command is transmitted, the firmware waits 500 ms
after key-up and repeats the 1500 ms hold while BLE-derived actual Power remains
on, even if desired changes back to on. It stops when the HID link disconnects,
waits 15 seconds for shutdown to settle, then reconciles the latest desired
state. A transmitted wake likewise completes before a newer desired-off request
is applied. This makes missed commands self-recovering without overlapping
transitions.

## Wake advertisement

The BLE manufacturer company ID is `0x0046`. Bleak exposes a 16-byte value for
that company ID: one rolling counter byte followed by a stable 15-byte token.
The token is specific to the user's original remote and belongs only in
`secrets.yaml`. Ordinary Power On begins after the persisted last-sent counter,
holds each successive value for a configurable dwell (1500 ms by default),
stops advertising for a genuine off-air gap of at least 500 ms, wraps after
`0xFF`, and continues until the projector establishes its HID connection. A
newer desired-off request is applied after that transition. The off-air
boundary prevents a projector standby scan/rejection state observed when
payloads were changed continuously as mains
returned. This also avoids relying on one rapid burst when shutdown, CEC or
another remote has left the receiver's rolling state out of sync.

A separate exact-counter action first creates an off-air boundary, then holds
one selected payload in the BLE advertisement for a configurable duration
(4000 ms by default) without changing the selected value. The firmware records
the most recently submitted counter and exposes per-attempt value and full-cycle
counts for diagnostics. Passive desktop BLE observation is not packet-complete:
host stacks may omit callbacks even when advertisements were submitted by the
ESP32.

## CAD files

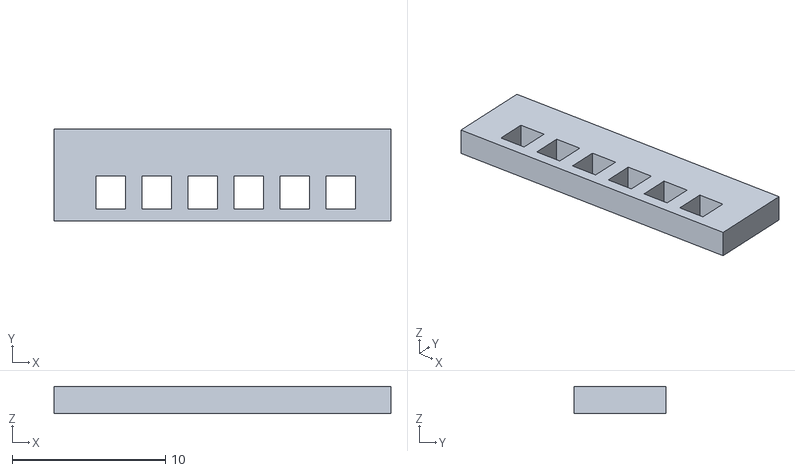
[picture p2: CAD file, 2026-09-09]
esp32-c3-with-OLED-mount-slim/esp32c3-end-stop.stl
22.0 x 6.00 x 1.78

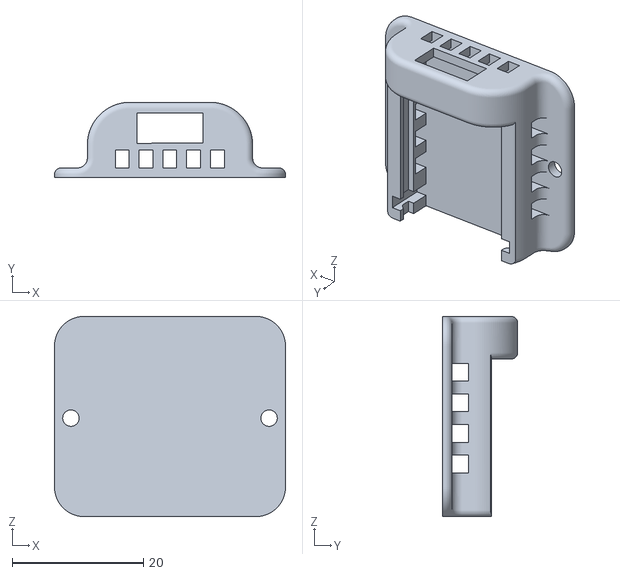
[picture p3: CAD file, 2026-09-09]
esp32-c3-with-OLED-mount-slim/esp32c3-mount-slim.stl
35.2 x 11.5 x 30.5

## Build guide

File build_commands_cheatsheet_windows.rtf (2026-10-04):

========================================================================
Build and Flash IR to Bluetooth Translater Under Windows via Powershell
========================================================================

cd to repository directory wherein YAML resides.
cd <drag your repository directory here and press return>

Create build environment
py -3 -m venv .venv

Install requirements using the local venv python executable
.venv\Scripts\python.exe -m pip install -r requirements.txt

Create secrets.yaml
.venv\Scripts\python.exe scripts\create_secrets.py --token "AA:BB:CC:DD:EE:FF:00:11:22:33:44:55:66:77:88"

Compile and Flash to ESP32 board (ESP32 is plugged into computer and makemine.yaml is your make file)
.venv\Scripts\esphome.exe run makemine.yaml

========================================================================
To Erase ESP32 Flash Memory in Windows
========================================================================

1. Determine com port to which your ESP32 is attached. Use built-in Windows command:
Get-CimInstance Win32_SerialPort | Select-Object DeviceID, Description

If command returns nothing, open Device Manager. Expand Ports (COM & LPT) section to find your board port.

2. Run one of the below erase commands. Use the one appropriate for you board.
Your specific port (e.g., COM3) should first be substituted into the appropriate command for your processor

For ESP32-C3
.venv\Scripts\esptool.exe --chip esp32c3 --port COM3 erase-flash

For ESP32-C6
.venv\Scripts\esptool.exe --chip esp32c6 --port COM3 erase-flash

For ESP32-S3
.venv\Scripts\esptool.exe --chip esp32s3 --port COM3 erase-flash

For Classic ESP32
.venv\Scripts\esptool.exe --chip esp32 --port COM3 erase-flash

NB: On some boards like classic ESP32, you may need to put board into flashing mode.
Hold down the physical "BOOT" button and continue holding it while clicking the "RESET" button.
After clicking "RESET" release "BOOT".
========================================================================

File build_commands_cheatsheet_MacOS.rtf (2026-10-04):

========================================================================
Build and Flash IR to Bluetooth Translater Under MacOS Using Terminal
========================================================================

cd to repository directory wherein YAML resides.
cd <drag your repository folder here and press return>

Create build environment and install python executable
python3 -m venv .venv
.venv/bin/python -m pip install -r requirements.txt

Create secrets.yaml
.venv/bin/python scripts/create_secrets.py --token "AA:BB:CC:DD:EE:FF:00:11:22:33:44:55:66:77:88"

Compile and flash to ESP32 board
.venv/bin/esphome run makemine.yaml

========================================================================
To Erase ESP32 Flash Memory in MacOS
========================================================================
Find device port on Mac. In Terminal type....

ls /dev/cu.*

Once device is found in listing, substitute it for port in one of the below commands.
The command you run depends on ESP32 processor (c3, c6, s3, classsic)

For ESP32-C3
.venv/bin/esptool --chip esp32c3 --port /dev/cu.usbmodem1101 erase-flash

For ESP32-C6
.venv/bin/esptool --chip esp32c6 --port /dev/cu.usbmodem1101 erase-flash

For ESP32-S3
.venv/bin/esptool --chip esp32s3 --port /dev/cu.usbmodem1101 erase-flash

For Classic ESP32
.venv/bin/esptool --chip esp32 --port /dev/cu.usbmodem1101 erase-flash

.venv/bin/esptool --chip esp32 --port /dev/cu.usbmodem1101 erase-flash
Execute that command in terminal to erase ESP32 board.

NB: On some boards like classic ESP32, you may need to put board into flashing mode.
Hold down the physical "BOOT" button and continue holding it while clicking the "RESET" button.
After clicking "RESET" release "BOOT".
========================================================================

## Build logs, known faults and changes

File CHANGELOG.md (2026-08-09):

# Changelog

All notable changes to this project are documented in this file.

## [2.23.0] - 2026-08-09

### Added

- Expose **Tap Duration** as a restored Home Assistant configuration number
  from 20–1000 ms, defaulting to the measured 100 ms original-remote timing.

### Changed

- Document every projector configuration entity and compile-time identity or
  Shortcut-label substitution, including ranges, defaults and interactions.

## [2.22.0] - 2026-08-09

### Fixed

- Hold ordinary keyboard and consumer-control taps for 100 ms by default using
  a non-blocking release timer, matching the measured original remote instead
  of sending key-down and key-up reports back-to-back.

## [2.21.0] - 2026-08-09

### Changed

- Make the four Home Assistant Shortcut button labels configurable without
  changing their stable entity IDs. Defaults describe the current projector
  assignments: HDMI 1, HDMI 2, HDMI 3 and 3D Settings.

## [2.20.0] - 2026-08-09

### Added

- Add a selectable exact-counter wake action with a configurable advertisement
  duration and a privacy-preserving desktop counter observer.

## [2.18.0] - 2026-08-04

### Added

- Add a stateful `Power` switch for the desired state and a read-only `Power`
  binary sensor backed by the projector's BLE HID connection.
- Expose the persisted last wake counter and per-attempt sweep diagnostics.

### Changed

- Replace the rapid 256-value wake burst with sequential counter advertisements
  held for 1500 ms and separated by a genuine 500 ms off-air gap.
- Persist the last advertised counter and continue from the next value until the
  projector connects.
- Use the configured Bluetooth identity for both HID and wake advertisements.

### Fixed

- Complete an already-transmitted transition before reconciling a newer desired
  state, so rapid `ON -> OFF -> ON` and `OFF -> ON -> OFF` changes converge.
- Repeat the confirmed 1500 ms held shutdown command after 500 ms release gaps
  until the projector disconnects.
- Wait 15 seconds after an observed shutdown before beginning a queued wake,
  preventing wake advertisements during the projector's shutdown transition.
- Adopt uncommanded projector changes from the original remote or HDMI-CEC as
  the new desired state.

## [2.10.0] - 2026-08-04

### Changed

- Make the Bluetooth HID and wake-advertisement identity configurable with
  `ble_remote_name`, defaulting to `M5Stack Atom Lite` so the Atom can coexist
  with the original remote. Choosing `XGIMI RC` exposes the projector's
  Shortcut settings but can replace or clash with an original remote pairing.

## [2.9.0] - 2026-08-04

### Added

- Initial shareable firmware for cloning the XGIMI Titan Noir Max Bluetooth
  remote on an M5Stack Atom Lite.

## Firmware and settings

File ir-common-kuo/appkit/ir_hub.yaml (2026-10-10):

# ir-common-kuo/ir-hub.yaml

#====================================================================
#=========================== IR Receiver ============================  
remote_receiver:
  id: ir_receiver
  pin:
    number: ${pin_ir_receiver}
    inverted: true
    mode:
      input: true
      pullup: true
  filter: 50us       
  idle: 10ms         
  tolerance: 35%     
  # dump:
  #   - raw
  #   - nec
  #   - jvc
  #   - sony
  #   - lg
  #   - panasonic
  #   - rc5
  #   - rc6
    
  # 1. Updates timestamp every single time ANY raw IR pulse or repeat packet burst hits the pin    
  on_raw:
    - lambda: |-
        id(global_last_raw_packet_time) = millis();

    - lambda: |-
        // 1. FAST BOUNDARY GUARD: Escape instantly if pulse stream array contains insufficient metrics
        size_t total_pulses = x.size();
        if (total_pulses < 2) return;

        // Re-added the explicit explicit array index brackets to satisfy the compiler and YAML parser
        uint32_t head_mark = x[0];
        
        // OPTIMIZED: Bitwise/conditional inversion instead of triggering math standard library std::abs()
        uint32_t head_space = (x[1] < 0) ? -x[1] : x[1];

        uint8_t proto = PROTO_UNKNOWN;

        // --- 1. MANCHESTER / SHORT-HEADER PROTOCOLS (RC5 & RC6) ---
        if (head_mark >= 700 && head_mark <= 1100 && total_pulses >= 18 && total_pulses <= 30) {
          proto = PROTO_RC5;
        }
        else if (head_mark >= 2400 && head_mark <= 2900 && head_space >= 700 && head_space <= 1100) {
          if (total_pulses >= 34 && total_pulses <= 46) {
            proto = PROTO_RC6;
          }
        }

        // --- 2. STANDARD SPACE/DISTANCE PROTOCOLS ---
        if (proto == PROTO_UNKNOWN) {
          // JVC Test: 8.4ms Mark / 4.2ms Space
          if (head_mark >= 7600 && head_mark < 8800 && head_space >= 3800 && head_space <= 4600) {
            proto = PROTO_JVC;
          }
          // SONY Test: Header pulse 2.4ms, short space < 900us, max 42 pulses
          else if (head_mark >= 2100 && head_mark <= 2700 && head_space < 900 && total_pulses <= 42) {
            proto = PROTO_SONY;
          }
          // PANASONIC Test: Header 3.4ms, space 1.7ms
          else if (head_mark >= 3100 && head_mark <= 3700 && head_space >= 1400 && head_space <= 2000) {
            proto = PROTO_PANASONIC;
          }
          // LG Test: Symmetric 4.5ms Mark / 4.5ms Space
          else if (head_mark >= 4000 && head_mark <= 4000 && head_space >= 4000 && head_space <= 4000) {
            proto = PROTO_LG;
          }
          // NEC / TViX Test: 9.0ms Mark
          else if (head_mark >= 8400 && head_mark <= 9400) {
            proto = PROTO_NEC;
          }
        }
        
        // --- 3. FALLBACK SANITY CHECK (For Headerless Repeat Packets) ---
        if (proto == PROTO_UNKNOWN) {
          if (total_pulses == 34 && head_mark >= 400 && head_mark <= 600 && head_space >= 1400 && head_space <= 1800) {
            proto = PROTO_JVC;
          }
          else if (total_pulses >= 24 && total_pulses <= 42 && head_space < 1000) {
            proto = PROTO_SONY;
          } 
          else if (total_pulses >= 64 && total_pulses <= 68) { proto = PROTO_NEC; }
          else if (total_pulses >= 96 && total_pulses <= 102) { proto = PROTO_PANASONIC; }
        }

        id(learn_detected_protocol) = proto;
        
        ESP_LOGD("IR_RECOGNIZER", "Detected Protocol: %s (Mark: %uus, Space: %uus, Pulses: %u)", 
         to_string(proto), (unsigned int)head_mark, (unsigned int)head_space, total_pulses);
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

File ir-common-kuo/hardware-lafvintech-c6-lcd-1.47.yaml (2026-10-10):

# Lafvintech board may require physical reset after flashing.
# Also, often needs boot button held at reset to enable flashing.
# Extra long delay required to allow power rails to settle.
# Otherwise, wifi will not intialize.

# ============= BEGIN Configuration Options KUO ==========

substitutions:
  pin_ir_receiver: GPIO1
  pin_indicator_LED: GPIO8
  pin_action_btn: GPIO9 # use boot button to start actions
  wifi_tx_power: "10.0dB"

# Core Architecture Declaration

esp32:
  board: esp32-c6-devkitc-1
  framework:
    type: esp-idf
# ============= END Configuration Options KUO ==========

esphome:
  on_boot:
    # 800.0f runs BEFORE the display (400.0f) initializes, giving us structural control
    - priority: 800.0
      then:
        - delay: 3.0s  # Required delay to allow physical power lines time to stabilize

    - priority: -100 # 4. Wait until the very end of the boot sequence when it is safe
      then:
        - light.turn_on:
            id: display_backlight
            brightness: 0.5
            
            
globals:
    # ======= myDisplay display globals
  - id: myDisplay_line1
    type: std::string  
    restore_value: no
    initial_value: ''

  - id: myDisplay_line2
    restore_value: no
    type: std::string  
    initial_value: ''
    
  - id: myDisplay_line3
    restore_value: no
    type: std::string  
    initial_value: ''
              
output:
  - platform: ledc
    pin: 
      number: GPIO22
      mode: OUTPUT        # Restores standard pushing power for the backlight circuit
    id: backlight_pwm
    frequency: 1000Hz     # Explicitly sets frequency for ESP-IDF stability
    min_power: 0.0
    max_power: 0.5
    
      
light:
  - platform: esp32_rmt_led_strip # neopixel
    id: indicator_led
    pin: ${pin_indicator_LED}
    chipset: WS2812
    num_leds: 1
    rgb_order: GRB
    name: "Sniffer Indicator"
    internal: true

  - platform: monochromatic  
    name: "Display Backlight"
    id: display_backlight
    output: backlight_pwm
    default_transition_length: 0s
    gamma_correct: 0          # Keeps response linear 
    restore_mode: ALWAYS_OFF    
    internal: true

script:
  - id: flash_led_custom
    parameters:
      count: int         # Number of flashes
      dwell: int         # duration of flash in msec
      red: float         # Red value (0.0 to 1.0)
      green: float       # Green value (0.0 to 1.0)
      blue: float        # Blue value (0.0 to 1.0)
    mode: queued
    then:
      - repeat:
          count: !lambda "return count;"
          then:
            # --- TURN RGB LED ON WITH DYNAMIC COLOR ---
            - light.turn_on:
                id: indicator_led
                red: !lambda "return red;"
                green: !lambda "return green;"
                blue: !lambda "return blue;"
                brightness: 0.2
                transition_length: 0s
            - delay: !lambda "return dwell;"

            # --- TURN RGB LED OFF ---
            - light.turn_off:
                id: indicator_led
                transition_length: 0s
            - delay: !lambda "return dwell;"
            
  - id: turn_led_on_custom
    parameters:
      red: float         # Red channel (0.0 to 1.0)
      green: float       # Green channel (0.0 to 1.0)
      blue: float        # Blue channel (0.0 to 1.0)
      brightness: float  # Brightness (0.0 to 1.0)
    mode: restart
    then:
      - light.turn_on:
          id: indicator_led
          red: !lambda "return red;"
          green: !lambda "return green;"
          blue: !lambda "return blue;"
          brightness: !lambda "return brightness;"
          transition_length: 0s  
          
  - id: turn_led_off_custom
    mode: restart
    then:
      - light.turn_off:
          id: indicator_led
          transition_length: 0s  


# ========  Display Specific Implementation ========

font:
  - file: "gfonts://Roboto"
    id: my_fontSmall
    size: 30
  - file: "gfonts://Roboto"
    id: my_fontMedium
    size: 35
  - file: "gfonts://Roboto"
    id: my_fontLarge
    size: 40

    
spi:
  clk_pin: GPIO7
  mosi_pin: GPIO6
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

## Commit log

2026-08-09 fix(power): reconcile projector transitions reliably
    Make desired power idempotent across rapid reversals, external remote or CEC changes, shutdown settling, repeated held shutdown attempts and persistent wake-counter sweeps. Continue using the configured Bluetooth identity throughout.
2026-08-09 feat: make shortcut labels configurable
    Describe the projector's current HDMI 1-3 and 3D assignments in Home Assistant while keeping stable ESPHome and entity IDs.
2026-08-09 fix: preserve original remote tap timing
    Hold ordinary keyboard and consumer reports for the measured 100 ms median using non-blocking release timers, while leaving the separate held-power timing unchanged.
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2026-08-12 Add files via upload
    Cleaned up commenting and renamed to indicate GPIO pin being used for IR input.
2026-08-13 Update README.md
    neater make file headers, changed to 3 volt supply as recommended wiring
2026-08-13 Add files via upload
    Changed naming convention to emphasize board type.
    Added JVC-VCR remote mappings
    [mrmachine_bluetooth.yaml]
2026-08-19 Add files via upload
    Reverted to older bluetooth stack to avoid desyncrhonization issues in recent bluetooth stack.
    Added ability for ESP32 to sniff wake tokens directly
    [mrmachine_bluetoothV_old.yaml, partitions.csv]
2026-08-19 Update README.md
    updated button tables to include token sniff, clear and recall functions
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2026-08-20 Add files via upload
    Added ability to define remote_name_ in "old" bluetooth stack. The old one had remote_name set as a constant. Now it accepts it can accept as data from each make file's substitutions.
    [mrmachine_bluetoothV_old.yaml]
2026-08-21 Add files via upload
    Sniffing while identical token has already stored no longer appears to fail.
    Added support for onboard LED light of boards C3 and C6
    Pressing BOOT button on ESP board is now alternate way to start sniffing mode
    [hardware_c3.yaml, hardware_c6.yaml, mrmachine_bluetoothV_old.yaml]
2026-08-21 Add files via upload
    Added hardware file for S3 boards
    [hardware_s3.yaml]
2026-08-21 Add files via upload
    m5 stack atom lite hardware file. Look in file for recommended pin assignments.
    [hardware_m5stack-atom-lite.yaml]
2026-08-21 Add files via upload
    changed rx to standard grove white and GPIO32
    [hardware_m5stack-atom-lite.yaml]
2026-08-21 Add files via upload
    revamp file structure in git
    [mrmachine_bluetoothV_old.yaml, partitions.csv]
2026-08-22 Add files via upload
    Implemented repeat with IR button held down.
    Fixed some IR mappings
    [hardware-c6.yaml]
2026-08-23 Add files via upload
    Added support of waveshare esp32 S3 LCD 1.47B
    [hardware-s3-waveshare-lcd-1.47B.yaml]
2026-08-23 Add files via upload
    Increased button press accepted speed. Allows nearly 10 button presses/sec by changing debounce to 100 msec.
2026-08-23 Add files via upload
    code refactoring
    [hardware-c3.yaml, hardware-c6.yaml, hardware-m5stack-atom-lite.yaml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]
2026-08-25 Add files via upload
    Changed to two button sequence for cleraring token (usually 5 then enter)
    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
    [hardware-c3.yaml, hardware-s3-waveshare-lcd-1.47B.yaml]
2026-08-27 Add files via upload
    Protocols not of interest to current IRmap better filtered out
    [hardware-s3-waveshare-lcd-1.47B.yaml]
2026-08-27 Add files via upload
    Improved backlight control for waveshare LCD. Adjusted some naming conventions.
    [hardware-s3-waveshare-lcd-1.47B.yaml]
2026-08-28 Add files via upload
    HOLDING boot button down for 5 seconds toggles display on/off. Setting is retained between boots.
    Click of boot button still starts sniffing for tokens.
    [hardware-s3-waveshare-lcd-1.47B.yaml]
2026-09-02 Add files via upload
    Boot button debounce adjusted and minor fixes
    [hardware-s3-hosyond-lcd-3.5-touch.yaml]
2026-09-04 Add files via upload
    Enhanced and verified Epson mapping
    [hardware-s3-waveshare-lcd-1.47B.yaml]
2026-09-06 Add files via upload
    fixed regression causing button repeating failure
2026-09-07 Add files via upload
    added hardware-s3-waveshare-esp32-s3-touch-lcd-2.8.yaml
    [hardware-s3-waveshare-esp32-s3-touch-lcd-2.8.yaml]
2026-09-14 Add files via upload
    Added switchable profiles and learning of up to 5 IR remotes.
    [hardware-c3.yaml, hardware-c6.yaml, hardware-m5stack-atom-lite.yaml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]
2026-09-20 Add files via upload
    Webserver version 3 features
    [mrmachine_bluetooth_V1.0.0.yaml]
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2026-09-20 Add files via upload
    Fix for rapid repeats in NEC remotes that fire rapid trains of NEC pulses.
    Changed right arrow mapping for BenQ
    [ir_hub.yaml]
2026-09-22 Add files via upload
    added c6-lafvintech-lcd-1.47 board
    [hardware-c6-lafvintech-lcd-1.47.yaml]
2026-09-22 Add files via upload
    Fixed neopixel color order
    [hardware-c6-lafvintech-lcd-1.47.yaml]
2026-09-23 Add files via upload
    Internal changes to unify profile storage index
    Fixed issue with learned profiles not fully activating post boot
    [ir_hub.yaml, make-esp32-TEMPLATE.yaml]
2026-09-23 Add files via upload
    WiFi power set per hardware file.
    [hardware-c3.yaml, hardware-c6-lafvintech-lcd-1.47.yaml, hardware-c6.yaml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]
2026-09-28 Add files via upload
    Added webserver with download and upload of profile csv files.
    [hardware-esp32-c6-wroom-1.yaml, hardware-hosyond-s3-lcd-3.5-touch.yaml, hardware-ideaspark-esp32-0.96-OLED.yaml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]
2026-09-29 Add files via upload
    Added ability to specify bluetooth raw keyboard and raw consumer reports in CSV files to override XGIMI Titan Noir bluetooth command mapping.
    [hardware-esp32-c6-wroom-1.yaml, hardware-hosyond-s3-lcd-3.5-touch.yaml, hardware-lafvintech-c6-lcd-1.47.yaml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]
2026-09-29 Add files via upload
    Bug fix: Corrected buttons that were mapped to differing button names not functioning.
    [mrmachine_bluetooth_V1.0.0.yaml]
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2026-10-03 Add files via upload
    Corrected regression in power_on and power_off behavior
    [ir_hub.yaml]
2026-10-03 Add files via upload
    Macro now support RKEY and RCON bluetooth codes
    [hardware-esp32-c3-0.42-OLED.yaml, mrmachine_bluetooth_V1.0.0.yaml, partitions.csv]
2026-10-04 Add files via upload
    HEAP and RAM usage optimized further - particularly important for C3 boards.
2026-10-04 Add files via upload
    Home Assistant API: removed to improve overall speed and stability of primary functionality, especially with C3's.
    [mrmachine_bluetooth_V1.0.0.yaml]
2026-10-05 Add files via upload
    Improved webserver heap efficiency
    [hardware-esp32-c3-0.42-OLED.yaml, hardware-esp32-c6-wroom-1.yaml, hardware-lafvintech-c6-lcd-1.47.yaml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]
2026-10-06 Add files via upload
    Major rewrite of mrmachine bluetooth stack to support button holds and RKEY / RCOM codes
    [mrmachine_bluetooth_V1.0.0.yaml]
2026-10-07 Add files via upload
    Major architecture fix for web and Home Assistant button pushing properly using RKEY and RCON bluetooth codes.
    Fixed focus_manual to stay on screen as long as when activated by original remote
    [mrmachine_bluetooth_V1.0.0.yaml]
2026-10-07 Add files via upload
    Changed macro csv formatting for better readability
    [mrmachine_bluetooth_V1.0.0.yaml, partitions.csv]
2026-10-08 Add files via upload
    Macros now allow recording of long button holds.
    [hardware-waveshare-s3-touch-lcd-2.8.yaml]
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2026-10-09 Add files via upload
    Improved recording and playback timing cadence
    Added compile option for use with non-Xgimi projectors.
    [hardware-esp32-c3-0.42-OLED.yaml, hardware-esp32-c6-wroom-1.yaml, hardware-heltec-hiletgo-s3-0.96-OLED-v3.yaml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]
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2026-10-10 Add files via upload
    Fixed some issues in profile and macro upload/download
    [hardware-esp32-c3-0.42-OLED.yaml, hardware-esp32-c6-wroom-1.yaml]
2026-10-10 Add files via upload
    higher timing resolution for button actions.
    [hardware-lafvintech-c6-lcd-1.47.yaml]
2026-10-18 Add files via upload
    macro_record and macro_play button debounce fix
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2026-10-27 Fixed Bluetooth Driver Unwanted Repeats
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
